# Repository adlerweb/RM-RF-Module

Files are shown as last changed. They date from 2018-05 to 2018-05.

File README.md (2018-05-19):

# RM-RF-Module

This system can be used to add RF functionality to ordinary photoelectric smoke detectors based on the widespread MC145010 IC or its derivatives.

The module uses RF24 2.4GHz transceivers and communicates with a central receiver. In addition to relaying the smoke alarm it also features a DS18B20 temperature sensor and will report high temperature conditions. Lastly I'll - even if no alarm is active - report battery voltage and temperature back to the central receiver in regular intervals to allow for statistics and detect broken detectors.

Power can be supplied using the original 9V battery or a protected 7.4V lithium battery pack.

Real time communication or mesh functionality is not implemented to keep power consumption down. It should be possible to use nodes as relays using this concept, but nothing has been implemented so far.

Please consider this project as WIP - if you're looking for a system that "just works" you're probably better off with a commercial system.
More details in German can be found in the design and build vlog over at HTTPS://www.youtube.com/user/adlerweb/search?query=rauchmelder

# Warning

Modifying detectors will void their approval. If you're required to install smoke detectors modified modules are not sufficient to pass the requirements. Use at your own risk.

# Repo

## Hardware

The module is based on a cheap ATTiny88 as central processor and an NRF24L01+ for radio communication. The 3.3V system power uses a NCP551 featuring a rather low quiescent current for it's price to keep consumption down. Peripherals like the radio module or an optional DS18B20 are only powered up when accessed.

The original smoke alarm uses the IO-functionality of the MC145010 detector IC. Additionally the onboard LED and (optionally) the switch are interfaced. Since the board is based on an older design with full separation the interface uses optocouplers between detector and this PCB. There is however no galvanic isolation. It should be possible to switch to a transistor based approach and shrink the PCB if desired.

## Software

### Basic function

All system timing is based on the regular LED flash of the original smoke detector IC. In my case it blinks every 20 seconds.

When booting for the first time all used GPIOs will be prepared and a boot message transmitted to the master.

Now the IO pin is checked for an alarm condition, if there is one an alarm message with type 1 will be transmitted.
Next - if the configured number of LED flashes for temperature is reached - the temperature sensor will be powered up and checked. If the measured temperature is above a defined alarm level an alarm message with type 2 will be transmitted
Now - if the configured number of LED flashes for the alive-message is reached - it will power up the temperature sensor and ADC, measure both and send the results to the master
Lastly it ensures the detectors LED is turned off, rearms the LED-flash-interrupt and enters power-down-mode.

### RF-Notes

NRF24L01+ only supports listening to 6 FIFOs at a time. While it is possible to target a single FIFO from multiple senders there are reports this would mess up the auto-ACK-feature in some cases and as such provide only unreliable communication. The code uses an additional checksum and acknowledgement layer to ensure proper transmission. Inside the ACK the master can piggyback a 2-byte-value to send commands to the smoke detector.

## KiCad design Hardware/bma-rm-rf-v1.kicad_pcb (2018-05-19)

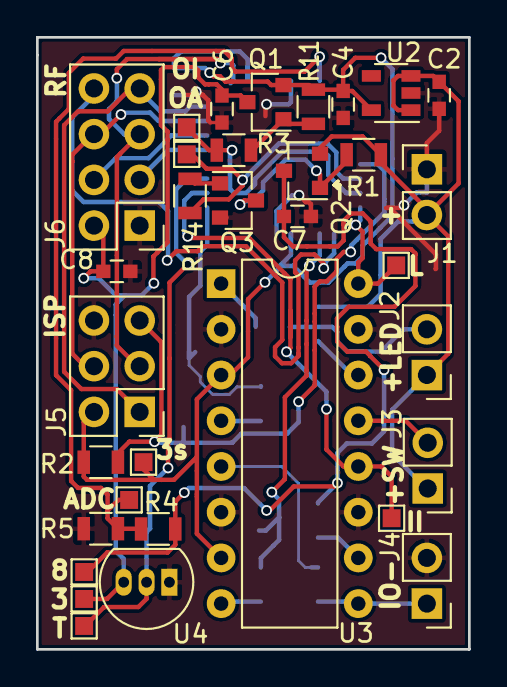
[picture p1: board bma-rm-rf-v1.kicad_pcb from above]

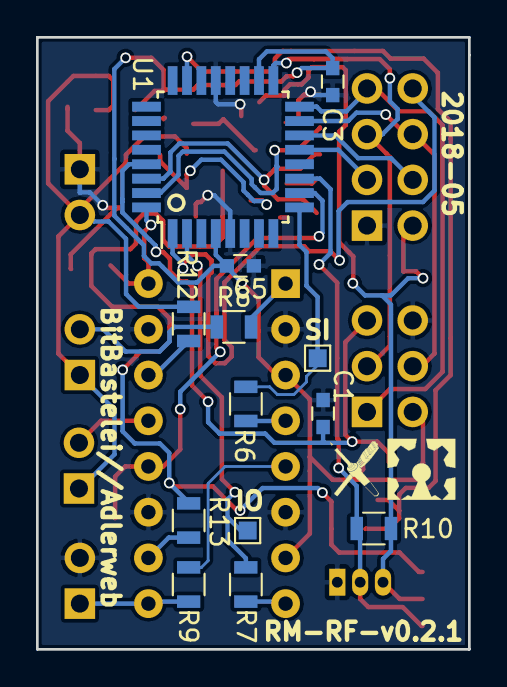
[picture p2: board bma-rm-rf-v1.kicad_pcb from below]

Board: 2 copper layers, 24.0 x 34.0 mm, 46 parts (13 on the bottom side), 32 nets.

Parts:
C1, C2, C3, C4, C5, C6, C7, C8: 100n; C_0603
J1: PWR; Pin_Header_Straight_1x02_Pitch2.54mm
J2: RM_LED; Pin_Header_Straight_1x02_Pitch2.54mm
J3: RM_SW; Pin_Header_Straight_1x02_Pitch2.54mm
J4: RM_IO; Pin_Header_Straight_1x02_Pitch2.54mm
J5: ISP; Pin_Header_Straight_2x03_Pitch2.54mm
J6: NRF24L01; Pin_Header_Straight_2x04_Pitch2.54mm
Q1, Q2: AO3407; SOT-23
Q3: SI2302DS; SOT-23
R1, R11: 560k; R_0805
R2, R10: 10k; R_0805
R3, R8, R9, R12, R13, R14: 1.8k; R_0805
R4: 22k; R_0805
R5: 12k; R_0805
R6, R7: 470; R_0805
TP1, TP2, TP3, TP4, TP5, TP6, TP7, TP8, TP9, TP10, TP11: TEST; Test_Point_Pad_1.0x1.0mm
U1: ATTINY88-AU; TQFP-32_7x7mm_Pitch0.8mm
U2: NCP551; SOT-23-5
U3: PC847; DIP-16_W7.62mm
U4: DS18B20; TO-92_Inline_Narrow_Oval

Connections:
+3.3VP: C6.1, C8.2, J6.2, Q1.3, R10.2, TP2.1, U4.3
+3V3: C3.1, C4.1, C5.1, J5.2, Q1.2, R2.1, R11.2, TP5.1, U1.4, U1.18, U2.5, U3.3, U3.7
+BATT: C2.1, J1.2, J2.1, J3.1, Q2.2, R1.2, R12.1, U2.1, U2.3
CE: J6.3, U1.13
CSN: J6.4, U1.14
GND: C1.1, C2.2, C3.2, C4.2, C5.2, C6.2, C7.2, C8.1, J1.1, J4.2, J5.6, J6.1, Q3.2, R5.2, U1.5, U1.21, U2.2, U3.2, U3.6, U3.11, U3.15, U4.1
INT0: J6.8, U1.1
MISO: J5.1, J6.7, U1.16
MOSI: J5.4, J6.6, U1.15
unnamed: J2.2, R8.1
unnamed: J3.2, U3.13
unnamed: J4.1, R9.1, U3.9
unnamed: Q1.1, R3.2, R11.1
unnamed: Q2.1, Q3.3, R1.1
unnamed: Q3.1, R14.2
unnamed: R4.2, R5.1, TP6.1, U1.23
unnamed: R6.1, U3.4
unnamed: R7.1, U3.8
unnamed: R8.2, U3.1
unnamed: R9.2, U3.5
unnamed: R12.2, U3.14
unnamed: R13.2, U3.10
PWR_ON_ADC: R14.1, TP3.1, U1.30
PWR_ON_IO: R3.1, TP1.1, U1.31
RESET: C1.2, J5.5, R2.2, U1.29
R_IO_I: TP10.1, U1.10, U3.12
R_IO_O: R7.2, TP9.1, U1.2
R_LED: TP8.1, U1.32, U3.16
R_SW: R6.2, TP7.1, U1.9
SCK: J5.3, J6.5, U1.17
TEMP: R10.1, TP11.1, U1.11, U4.2
VPP: C7.1, Q2.3, R4.1, R13.1, TP4.1

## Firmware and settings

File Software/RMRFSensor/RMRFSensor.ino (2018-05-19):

#include <SPI.h>
#include "RF24.h"
#include <OneWire.h>
#include <avr/sleep.h>

#define SLEEP_STAT 300 //Seconds between statistic packets
#define SLEEP_CHK  60  //Seconds between checking temperature

#define LED_INTV   20  //Seconds between led blinks

#define TEMP_ALARM 4500 //Send alarm for >=45.00°C

/* ADCM = Vcc/1023 * ((R1+R2) / R2) * 100 */
#define ADCM 0.908304949163355

//#define DEBUG 1

#define ON_ADC 0
#define ON_SYS 1
#define ONE_WIRE_BUS 7

#define IO_LED_INT 2
#define IO_LED 6
#define IO_IO_I 3
#define IO_IO_O 4
#define IO_SW_O 5

bool radioId = 1;
byte addresses[][6] = {"RM1RX","RN001"};

RF24 radio(9, 10);

bool st_sys = false;
bool st_adc = false;

byte lednum = 1;
volatile bool ledflag = false;

byte lastCmd = 0x00;

uint16_t gen_chk(uint16_t rid, const uint8_t *data, uint16_t size)
{
    //Basically CRC16 with radioID XOR 0xAAAA as polynom
    rid ^= 0xAAAA;
    
    uint16_t out = 0;
    int bits_read = 0, bit_flag;

    /* Sanity check: */
    if(data == NULL)
        return 0;

    while(size > 0)
    {
        bit_flag = out >> 15;

        /* Get next bit: */
        out <<= 1;
        out |= (*data >> bits_read) & 1; // item a) work from the least significant bits

        /* Increment bit counter: */
        bits_read++;
        if(bits_read > 7)
        {
            bits_read = 0;
            data++;
            size--;
        }

        /* Cycle check: */
        if(bit_flag)
            out ^= rid;

    }

    // item b) "push out" the last 16 bits
    unsigned int i;
    for (i = 0; i < 16; ++i) {
        bit_flag = out >> 15;
        out <<= 1;
        if(bit_flag)
            out ^= rid;
    }

    // item c) reverse the bits
    uint16_t crc = 0;
    i = 0x8000;
    unsigned int j = 0x0001;
    for (; i != 0; (i >>=1, j <<= 1)) {
        if (i & out) crc |= j;
    }

    return crc;
}

bool sendString(String output) {
  char cout[(output.length()+1)];
  byte retry = 5;
  byte i = 0;
  unsigned long started_waiting_at;
  boolean timeout = false;

  output.toCharArray(cout, (output.length()+1));
  
  unsigned int chk = gen_chk(radioId, cout, strlen(cout));

  bool ls = on_sys();
  if(!on_nrf()) return false;

  while(retry > 0) {
    radio.stopListening();
    
    radio.write(&cout, strlen(cout));
  
    radio.startListening();
    started_waiting_at = micros();
    timeout = false;
    
    while ( ! radio.available() ){
      if (micros() - started_waiting_at > 200000 ){ // 200ms
          timeout = true;
          break;
      }
    }

    if(!timeout) {
      
      unsigned int in[2];
      radio.read( &in, 2*sizeof(unsigned int));
      if(in[0] == chk) {
        radio.stopListening();
        if(ls) off_sys();
        lastCmd = in[1];
        return true;
      }
    }
    retry--;
    delay(50);
  }
  
  radio.stopListening();

  if(ls) off_sys();
  
  return false;
}

bool on_sys(void) {
  if(st_sys) return false;
  digitalWrite(ON_SYS, LOW);
  delay(25);
  st_sys = true;
  return true;
}
bool off_sys(void) {
  if(!st_sys) return false;
  digitalWrite(ON_SYS, HIGH);
  st_sys = false;
  return true;
}

bool on_adc(void) {
  if(st_adc) return false;
  digitalWrite(ON_ADC, HIGH);
  delay(25);
  st_adc = true;
  return true;
}
bool off_adc(void) {
  if(!st_adc) return false;
  digitalWrite(ON_ADC, LOW);
  st_adc = false;
  return true;
}

void on_sw(void) {
  digitalWrite(IO_SW_O, LOW);
}
void off_sw(void) {
  digitalWrite(IO_SW_O, HIGH);
}

void on_io(void) {
  digitalWrite(IO_IO_O, HIGH);
}
void off_io(void) {
  digitalWrite(IO_IO_O, LOW);
}

bool on_nrf(void) {
  if(!st_sys) return false;
  
  radio.begin();
  radio.setPALevel(RF24_PA_HIGH);
  radio.setAutoAck(true);
  radio.setDataRate(RF24_250KBPS);
  radio.setChannel(0x70);
  
  radio.openWritingPipe(addresses[0]);
  radio.openReadingPipe(1,addresses[1]);

  return true;
}

signed int get_temperature() {
  bool ls=on_sys();
  
  OneWire ds(ONE_WIRE_BUS);
  byte addr[8];
  byte data[12];
  byte present = 0;
  byte i = 0;
  float celsius;

  ds.reset();
  ds.reset_search();
  ds.search(addr);

  if(addr[0] != 0x28) return 851;

  ds.reset();
  ds.select(addr);
  ds.write(0x44,1);
  delay(760);      // conversion takes <=750ms

  present = ds.reset();
  ds.select(addr);    
  ds.write(0xBE);   // Read Scratchpad

  for ( i = 0; i < 9; i++)
  {
    data[i] = ds.read();
  }

  int16_t raw = (data[1] << 8) | data[0];
  celsius = (float)raw / 16.0;

  if(ls) off_sys();
  
  return (signed int)(celsius*100);
}

unsigned int get_adc() {
  bool ls=on_adc();

  unsigned int adc = analogRead(A0);
  
  adc = (unsigned int)((float)adc * ADCM);
  
  if(ls) off_adc();
  
  return (signed int)adc;
}

void sendTemp(void) {
  bool ls=on_sys();
  signed int dstemp;
  sendMsg('t', (String)get_temperature());
  if(ls) off_sys();
}

void sendBat(void) {
  bool ls=on_sys();
  sendMsg('b', (String)get_adc());
  if(ls) off_sys();
}

bool sendStats(void) {
  bool ls=on_sys();
  sendBat();
  sendTemp();
  if(ls) off_sys();
  return true;
}

void sendAlarm(byte source) {
  sendMsg('a', String(source, DEC));
  delay(1000);
}

void sendMsg(char type, String text) {
  String out="";
  out = (String)radioId+";"+type+";"+text;
  sendString(out);
}

void ledInt(void) {
  ledflag = true;
  detachInterrupt(digitalPinToInterrupt(IO_LED_INT));
}

void onLed(void) {
  attachInterrupt(digitalPinToInterrupt(IO_LED_INT), ledInt, LOW);
}

void setup() {
  pinMode(ON_SYS, OUTPUT);
  pinMode(ON_ADC, OUTPUT);
  pinMode(IO_IO_O, OUTPUT);
  pinMode(IO_SW_O, OUTPUT);

  pinMode(IO_LED, INPUT_PULLUP);
  pinMode(IO_LED_INT, INPUT_PULLUP);
  pinMode(IO_IO_I, INPUT_PULLUP);

  off_sw();
  off_sys();
  off_adc();
  off_io();

  sendMsg('B', "boot");
  
  onLed();
}

void loop() {

  if(digitalRead(IO_IO_I) == LOW) {
    //ALARM
    sendAlarm(1);
  }

  if((lednum % (byte)(SLEEP_CHK/LED_INTV)) == 0) {
    signed int dstemp = get_temperature();
    if(dstemp >= TEMP_ALARM && dstemp != 8500) {
      sendAlarm(2);
    }
    #ifdef DEBUG
      sendMsg('T', String(dstemp, DEC));
      delay(1000);
    #endif
  }
  
  if(lednum > (byte)(SLEEP_STAT/LED_INTV)) {
    sendStats();
    lednum = 0;
  }

  switch(lastCmd) {
    case 0x00:
    case 0xFF:
      //NOOP
      break;
    case 0x10:
      //Manueller Alarm aus
      off_io();
      break;
    case 0x11:
      //Manueller Alarm ein
      on_io();
      break;
    case 0x20:
      //Manuell Taster aus
      off_sw();
      break;
    case 0x21:
      //Manuell Taster ein
      on_sw();
      break;
    //@todo quick press switch
    //@todo modify ADCM
  }
  lastCmd=0x00;

  delay(25);
  
  if(digitalRead(IO_LED) == HIGH) {
    lednum++;
    ledflag = false;
    set_sleep_mode(SLEEP_MODE_PWR_DOWN);
    sleep_enable();
    onLed();
    sleep_mode();
    sleep_disable();
    #ifdef DEBUG
      sendMsg('w', String(lednum, DEC));
      delay(1000);
    #endif
  }
} // Loop

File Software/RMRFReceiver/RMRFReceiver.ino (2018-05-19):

#include <SPI.h>
#include "RF24.h"

RF24 radio(9, 10);

const byte addr_me[6] = "RM1RX";
const byte addr_dummy[6] = "DUMMY";

#define SENDQLEN 16
byte sendq[SENDQLEN];

uint16_t gen_chk(uint16_t rid, const uint8_t *data, uint16_t size)
{
    //Basically CRC16 with radioID XOR 0xAAAA as polynom
    rid ^= 0xAAAA;
    
    uint16_t out = 0;
    int bits_read = 0, bit_flag;

    /* Sanity check: */
    if(data == NULL)
        return 0;

    while(size > 0)
    {
        bit_flag = out >> 15;

        /* Get next bit: */
        out <<= 1;
        out |= (*data >> bits_read) & 1; // item a) work from the least significant bits

        /* Increment bit counter: */
        bits_read++;
        if(bits_read > 7)
        {
            bits_read = 0;
            data++;
            size--;
        }

        /* Cycle check: */
        if(bit_flag)
            out ^= rid;

    }

    // item b) "push out" the last 16 bits
    unsigned int i;
    for (i = 0; i < 16; ++i) {
        bit_flag = out >> 15;
        out <<= 1;
        if(bit_flag)
            out ^= rid;
    }

    // item c) reverse the bits
    uint16_t crc = 0;
    i = 0x8000;
    unsigned int j = 0x0001;
    for (; i != 0; (i >>=1, j <<= 1)) {
        if (i & out) crc |= j;
    }

    return crc;
}

void setup() {
  
  Serial.begin(115200);
  Serial.println(F("RMRF-RX"));

  for(byte i=0; i<SENDQLEN; i++) {
    sendq[i] = 0x00;
  }

  Serial.println();
  Serial.print(F("Init Radio..."));
  radio.begin();
  Serial.print(F("OK!\r\nParameters..."));
  radio.setPALevel(RF24_PA_HIGH);
  radio.setDataRate(RF24_250KBPS);
  radio.setChannel(0x70);
  Serial.print(F("OK!\r\nFIFOs..."));
  
  radio.openWritingPipe(addr_dummy);
  radio.openReadingPipe(1,addr_me);
  
  Serial.println(F("OK!"));
  radio.printDetails();
  radio.setAutoAck(true);
  Serial.print(F("RX..."));
  
  // Start the radio listening for data
  radio.startListening();
  Serial.println(F("OK!"));
}

void loop() {

  unsigned long got_time;
  char in[10];
  byte len;
  byte i;
  unsigned int radioId = 12345;
  byte addr_send[6];
  
  if( radio.available()){
                                                                  // Variable for the received timestamp
    while (radio.available()) {
      radio.read( &in, 9 );
   
      Serial.print(F("Got packet: "));
      Serial.print(in);
      Serial.print(" - ");
      
      //get radioId
      radioId = 0;
      i=0;
      while(in[i] != ';' && i<strlen(in)) {
        radioId <<= 8;
        radioId |= in[i]-0x30;
        i++;
      }
      
      Serial.print(F("Sender: "));
      Serial.print(radioId);
      Serial.print(" - ");

      sprintf(addr_send, "RN%03d", radioId);
      Serial.print(F("SendID: "));
      for(i=0; i<strlen(addr_send); i++) {
        Serial.print((char)(addr_send[i]));
      }
      Serial.print(" - ");
      
      radio.openWritingPipe(addr_send);

      unsigned int chk[2];
      chk[0] = gen_chk(radioId, in, strlen(in));
      chk[1] = 0x00;

      if(radioId < SENDQLEN) {
        chk[1] = sendq[radioId];
      }
      
      Serial.print(F("CHK: 0x"));
      Serial.print(chk[0], 16);
      Serial.print(F(" - CMD: 0x"));
      Serial.print(chk[1], 16);
      Serial.print(" - ");
      
      radio.stopListening();
      char addrtx = ("RN"+(String)radioId).c_str();
      //radio.openWritingPipe(addrtx);
      if(radio.write(&chk, 2*sizeof(unsigned int))) {
        Serial.println("OK");
        if(radioId < SENDQLEN) {
          sendq[radioId]=0x00;
        }
      }else{
        Serial.println("UKN");
      }
      radio.startListening();
    }
  }

  if(Serial.available()) {
    if(Serial.read() == "@") {
      //@;radioid;command;
      byte num = Serial.parseInt();
      byte val = Serial.parseInt();
  
      if(num == 0 || num > SENDQLEN) {
        //Serial.println("Index error");
      }else{
        Serial.print("Queueing Node 0x");
        Serial.print(num, HEX);
        Serial.print(" with Command 0x");
        Serial.println(val, HEX);
        sendq[num] = val;
      }
    } //@
  }//Serial
} // Loop
